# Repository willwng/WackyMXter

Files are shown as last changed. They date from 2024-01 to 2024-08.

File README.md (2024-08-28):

# WackyMXter
my custom keyboard.







## Features
- Wireless (bluetooth)
- Split (two halves can also be independent)
- Supports Choc and MX hotswap switches
- Ergonomic (for my hands at least)
- ZMK Support

## Project Format
- `gerber/`: Gerber files for the left and right side (includes BOM and placement files for assembly of shift register and diodes)
- `layout-editor/`: Layout of the keyboard for use at [keyboard layout editor](http://www.keyboard-layout-editor.com/)
- `pcb/`: KiCad files
- `zmk-firmware/`: Links to the ZMK firmware repo: [WackyMXter-zmk-firmware](https://github.com/willwng/WackyMXter-zmk-config)

## Materials
| **Item** | **Quantity Required (per set)** |
|---|---|
| PCBs | 2 |
| [Xiao BLE](https://www.seeedstudio.com/Seeed-XIAO-BLE-nRF52840-p-5201.html) | 2 |
| Rotary Encoder | 2 |
| Encoder Knob | 2 |
| Hotswap Sockets | 68 |
| Choc Switches | 68 |
| Power Switch | 2 |
| JST Battery Connector | 2 |
| LiPo Battery | 2 |
| Keycaps | 68 |

The power switch, JST connector, and LiPo battery are optional if you want the board to be wired (but this requires powering both halves)

## Notes
- Unless you update the footprint, be sure to get EC11(E) rotary encoder <- "E" being the key. I got an EC11(R) encoder and the legs didn't fit, causing me to clip them.
- I messed up the placement of the JST connector - it stands higher than the hotswap sockets, so for a caseless build it is unfortunately too tall to be on the bottom. I ended up mounting it on the front, but backward (to not interfere with the power switch), so this required reversing the polarity of the batteries

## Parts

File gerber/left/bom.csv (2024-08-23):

Designator | Footprint | Quantity | Value | LCSC Part #
D1, D10, D11, D12, D13, D14, D15, D16, D17, D18, D19, D2, D20, D21, D22, D23, D24, D25, D26, D27, D28, D29, D3, D30, D31, D32, D33, D34, D4, D5, D6, D7, D8, D9 | HybridDiode | 34 | Diode
U2 | SOP-16_3.9x9.9mm_P1.27mm | 1 | 74HC595

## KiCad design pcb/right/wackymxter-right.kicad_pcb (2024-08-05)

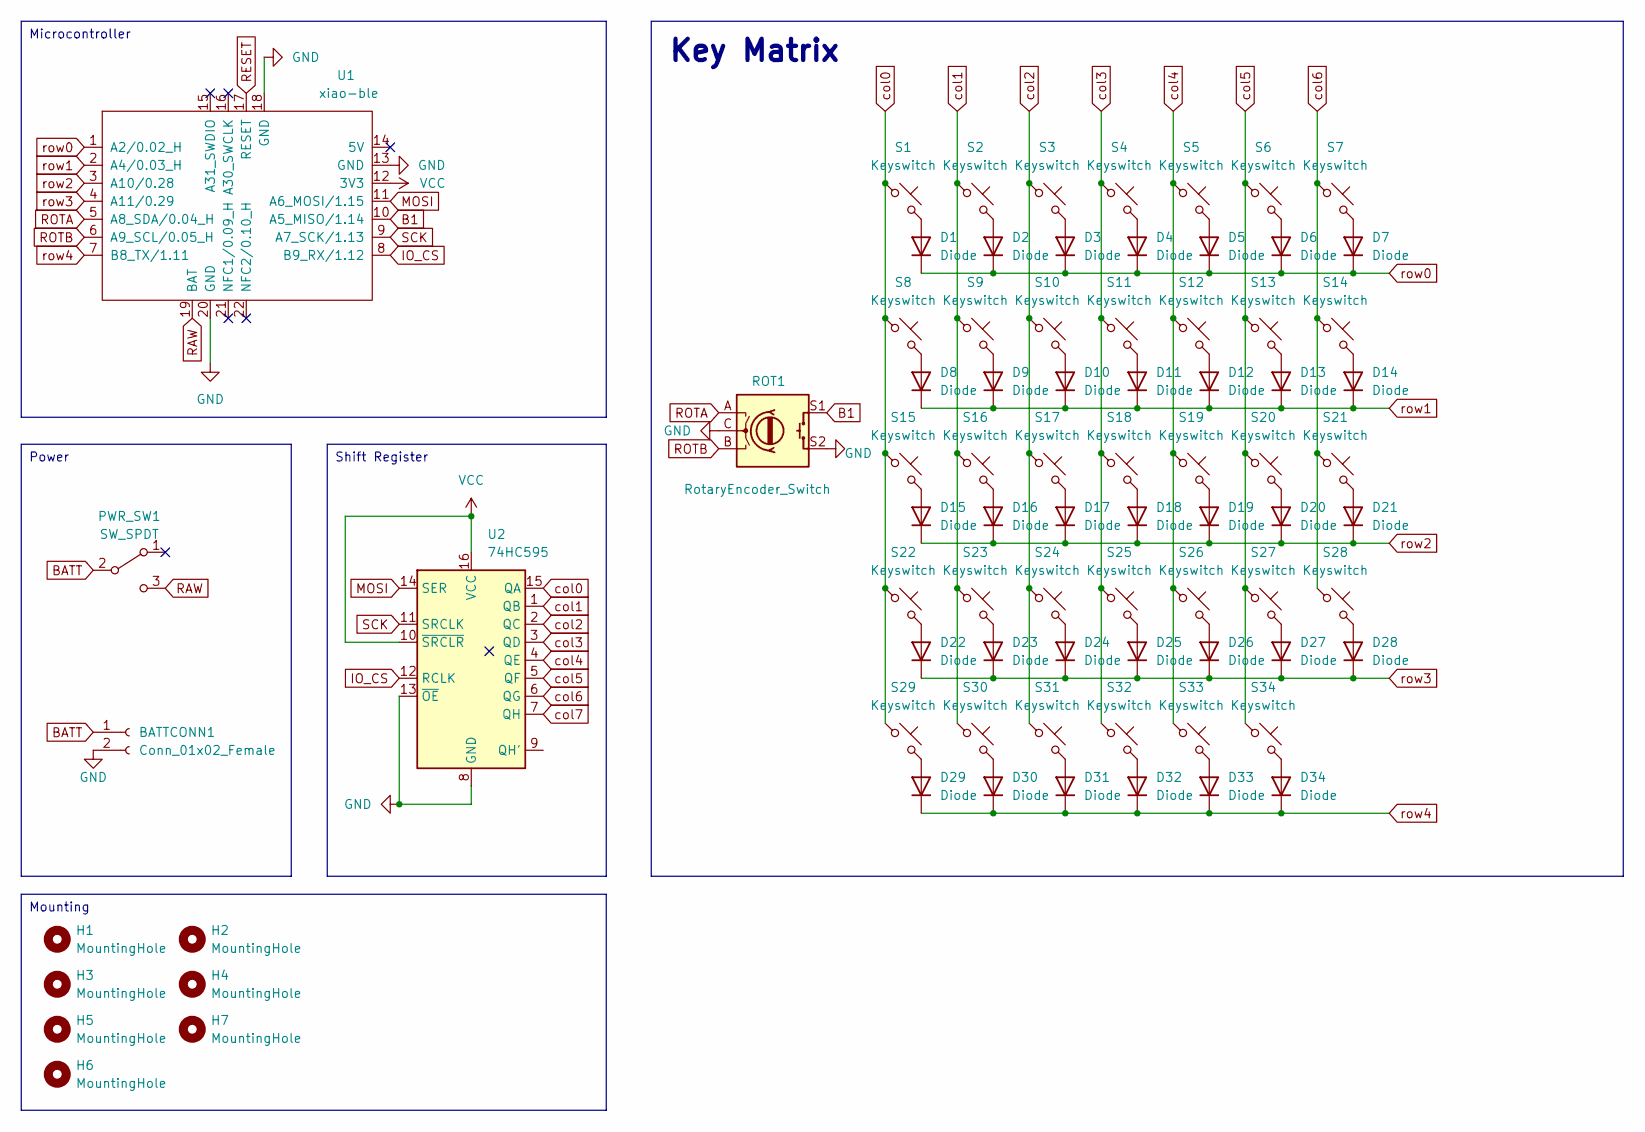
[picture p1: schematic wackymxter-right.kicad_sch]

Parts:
BATTCONN1: Conn_01x02_Female; JST_PH_S2B-PH-K_1x02_P2.00mm_Horizontal
D1, D2, D3, D4, D5, D6, D7, D8, D9, D10, D11, D12, D13, D14, D15, D16, D17, D18, D19, D20, D21, D22, D23, D24, D25, D26, D27, D28, D29, D30, D31, D32, D33, D34: Diode; HybridDiode
H1, H2, H3, H4, H5, H6, H7: MountingHole; MountingHole_2.2mm_M2
PWR_SW1: SW_SPDT; SW_SPDT_CK_JS102011SAQN
ROT1: RotaryEncoder_Switch; RotaryEncoder_Alps_EC11E-Switch_Vertical_H20mm
S1, S2, S3, S4, S5, S6, S7, S8, S9, S10, S11, S12, S13, S14, S15, S16, S17, S18, S19, S20, S21, S22, S23, S24, S25, S26, S27, S28, S29, S30, S31, S32, S33, S34: Keyswitch; MX_Choc_Hotswap
U1: xiao-ble; xiao-ble-smd-cutout
U2: 74HC595; SOP-16_3.9x9.9mm_P1.27mm

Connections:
B1: ROT1.S1, U1.10 (A5_MISO/1.14)
BATT: BATTCONN1.1, PWR_SW1.2 (B)
GND: BATTCONN1.2, ROT1.C, ROT1.S2, U1.13 (GND), U1.18 (GND), U1.20 (GND), U2.8 (GND), U2.13 (~OE)
IO_CS: U1.8 (B9_RX/1.12), U2.12 (RCLK)
MOSI: U1.11 (A6_MOSI/1.15), U2.14 (SER)
unnamed: D1.2 (A), S1.2
unnamed: D2.2 (A), S2.2
unnamed: D3.2 (A), S3.2
unnamed: D4.2 (A), S4.2
unnamed: D5.2 (A), S5.2
unnamed: D6.2 (A), S6.2
unnamed: D7.2 (A), S7.2
unnamed: D8.2 (A), S8.2
unnamed: D9.2 (A), S9.2
unnamed: D10.2 (A), S10.2
unnamed: D11.2 (A), S11.2
unnamed: D12.2 (A), S12.2
unnamed: D13.2 (A), S13.2
unnamed: D14.2 (A), S14.2
unnamed: D15.2 (A), S15.2
unnamed: D16.2 (A), S16.2
unnamed: D17.2 (A), S17.2
unnamed: D18.2 (A), S18.2
unnamed: D19.2 (A), S19.2
unnamed: D20.2 (A), S20.2
unnamed: D21.2 (A), S21.2
unnamed: D22.2 (A), S22.2
unnamed: D23.2 (A), S23.2
unnamed: D24.2 (A), S24.2
unnamed: D25.2 (A), S25.2
unnamed: D26.2 (A), S26.2
unnamed: D27.2 (A), S27.2
unnamed: D28.2 (A), S28.2
unnamed: D29.2 (A), S29.2
unnamed: D30.2 (A), S30.2
unnamed: D31.2 (A), S31.2
unnamed: D32.2 (A), S32.2
unnamed: D33.2 (A), S33.2
unnamed: D34.2 (A), S34.2
RAW: PWR_SW1.3 (C), U1.19 (BAT)
RESET: U1.17 (RESET)
ROTA: ROT1.A, U1.5 (A8_SDA/0.04_H)
ROTB: ROT1.B, U1.6 (A9_SCL/0.05_H)
SCK: U1.9 (A7_SCK/1.13), U2.11 (SRCLK)
VCC: U1.12 (3V3), U2.10 (~SRCLR), U2.16 (VCC)
col0: S1.1, S8.1, S15.1, S22.1, S29.1, U2.15 (QA)
col1: S2.1, S9.1, S16.1, S23.1, S30.1, U2.1 (QB)
col2: S3.1, S10.1, S17.1, S24.1, S31.1, U2.2 (QC)
col3: S4.1, S11.1, S18.1, S25.1, S32.1, U2.3 (QD)
col4: S5.1, S12.1, S19.1, S26.1, S33.1, U2.4 (QE)
col5: S6.1, S13.1, S20.1, S27.1, S34.1, U2.5 (QF)
col6: S7.1, S14.1, S21.1, S28.1, U2.6 (QG)
col7: U2.7 (QH)
row0: D1.1 (K), D2.1 (K), D3.1 (K), D4.1 (K), D5.1 (K), D6.1 (K), D7.1 (K), U1.1 (A2/0.02_H)
row1: D8.1 (K), D9.1 (K), D10.1 (K), D11.1 (K), D12.1 (K), D13.1 (K), D14.1 (K), U1.2 (A4/0.03_H)
row2: D15.1 (K), D16.1 (K), D17.1 (K), D18.1 (K), D19.1 (K), D20.1 (K), D21.1 (K), U1.3 (A10/0.28)
row3: D22.1 (K), D23.1 (K), D24.1 (K), D25.1 (K), D26.1 (K), D27.1 (K), D28.1 (K), U1.4 (A11/0.29)
row4: D29.1 (K), D30.1 (K), D31.1 (K), D32.1 (K), D33.1 (K), D34.1 (K), U1.7 (B8_TX/1.11)

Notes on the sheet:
Microcontroller
Power
Shift Register
Key Matrix
Mounting

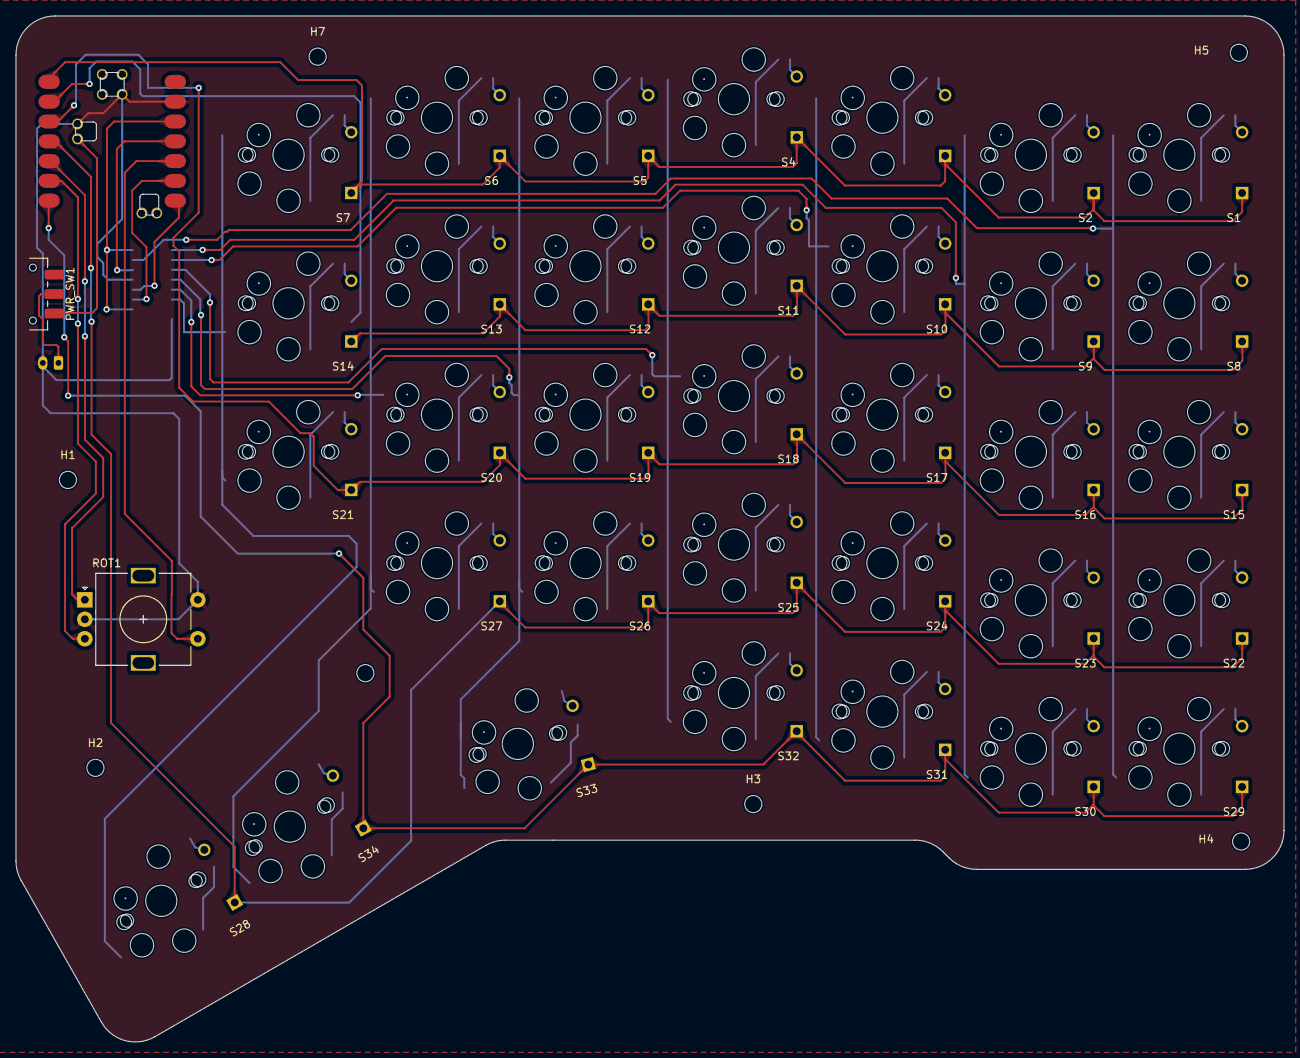
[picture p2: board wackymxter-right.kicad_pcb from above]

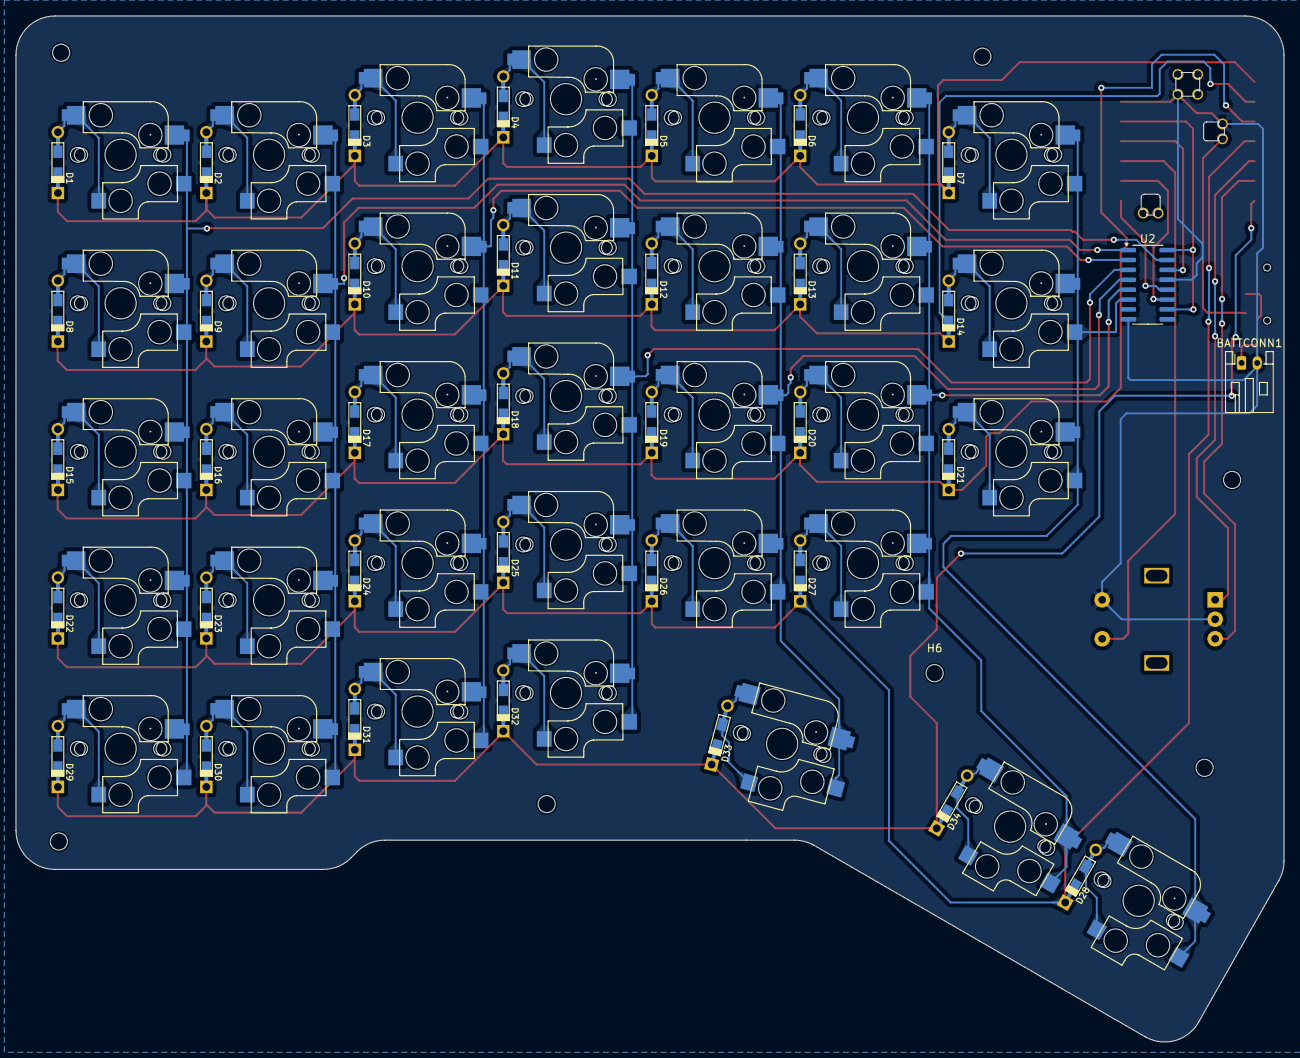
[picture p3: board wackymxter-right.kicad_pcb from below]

Board: 2 copper layers, 162.7 x 131.6 mm, 80 parts (3 on the bottom side), 56 nets.

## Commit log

2023-12-23 [KiCAD] start 35 key layout
    [wackymxter.kicad_pcb, wackymxter.kicad_sch]
2023-12-23 [KiCAD] switch to RP2040
    [wackymxter.kicad_pcb, wackymxter.kicad_sch]
2023-12-24 [KiCAD] V0.1: fully connected pcb
    [wackymxter.kicad_pcb, wackymxter.kicad_sch]
2023-12-24 [KiCAD] Pi Pico W with LEDs and Rotary Encoder
    [wackymxter.kicad_pcb, wackymxter.kicad_sch]
2023-12-26 [KiCAD] rev 0.3: dual diodes, optional hotswap
    [wackymxter.kicad_pcb, wackymxter.kicad_sch]
2024-01-02 [KiCAD] draft of left and right with 1.5u and fully connected
    [wackymxter-right.kicad_pcb, wackymxter-right.kicad_sch, wackymxter.kicad_pcb]
2024-01-04 [KiCAD] better copper fills
    [wackymxter-right.kicad_pcb]
2024-07-31 Insane progresgress
    [wackymxter-right.kicad_pcb, wackymxter-right.kicad_sch, wackymxter_left.dsn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]
2024-08-05 Cooler cutout out and match schematics
    [wackymxter-right.kicad_pcb, wackymxter-right.kicad_sch, wackymxter_left.kicad_pcb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]
